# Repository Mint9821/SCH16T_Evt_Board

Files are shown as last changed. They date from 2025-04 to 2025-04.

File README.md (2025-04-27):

# SCH16T_Evt_Board

Murata製IMUであるSCH16Tシリーズの開発ボード
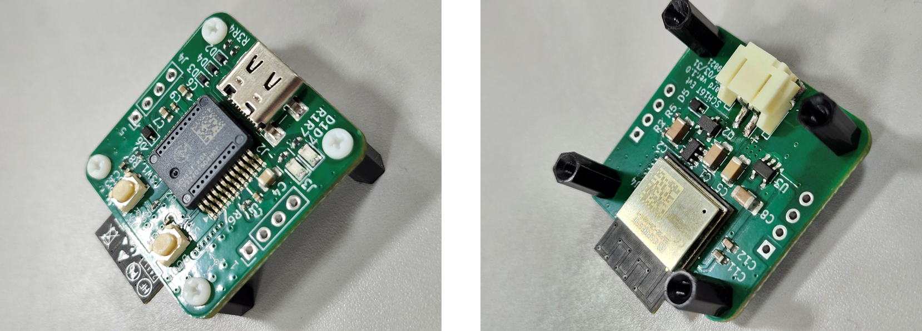
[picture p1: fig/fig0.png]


## システム構成図
本基板のシステム構成図を次に示す。
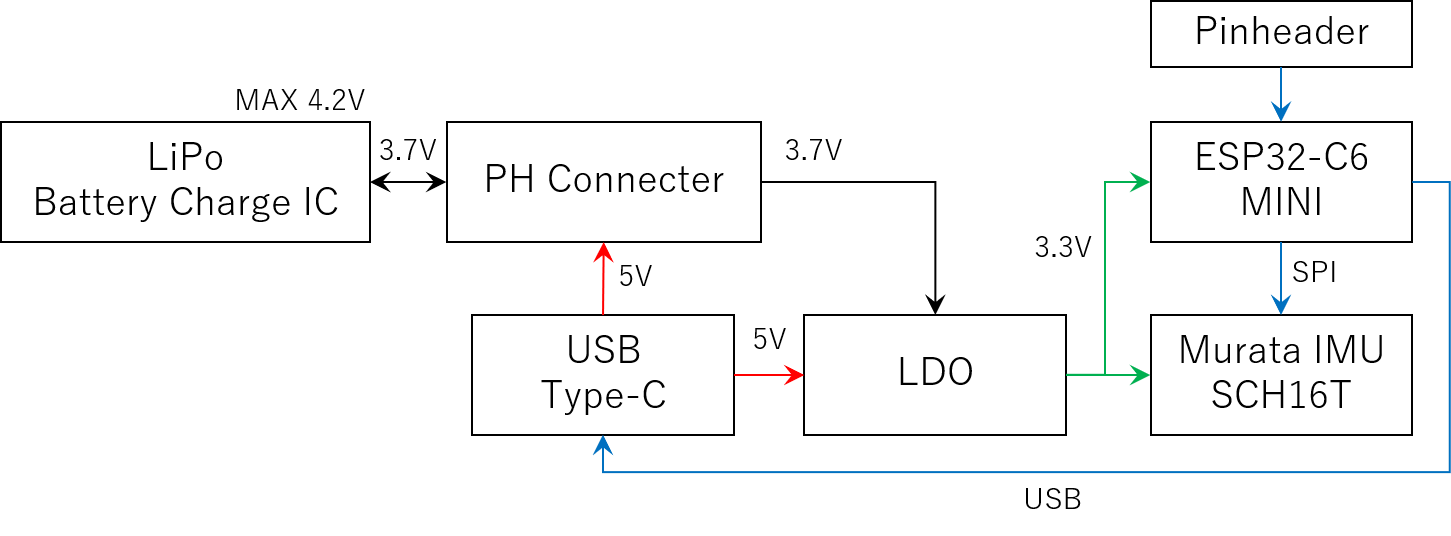
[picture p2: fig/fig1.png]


### 電源構成
USB-TypeCから5Vを給電でき、1SのLiPoバッテリを充電する機能を有する。
LiPoバッテリの充電中は、USBからの給電でマイコン及びIMUは駆動する。
LiPoバッテリが接続された状態でUSBを抜くと、LiPoバッテリからの給電に切り替わる。
5Vまたは3.7Vは低損失LDOによって3.3Vまで降圧される。

### 通信
マイコンとIMUはSPI通信で接続される。
また、マイコンからUSB-TypeCにはUSB通信で接続される。
マイコンにプログラムを書き込む場合は、USB-TypeCとPCを接続して行う。

## 1S LiPoバッテリの充電回路
先述した通り、USBコネクタを接続している間はLiPoバッテリが給電される。
回路動作の確認にはLTSpiceを用いて検証した。
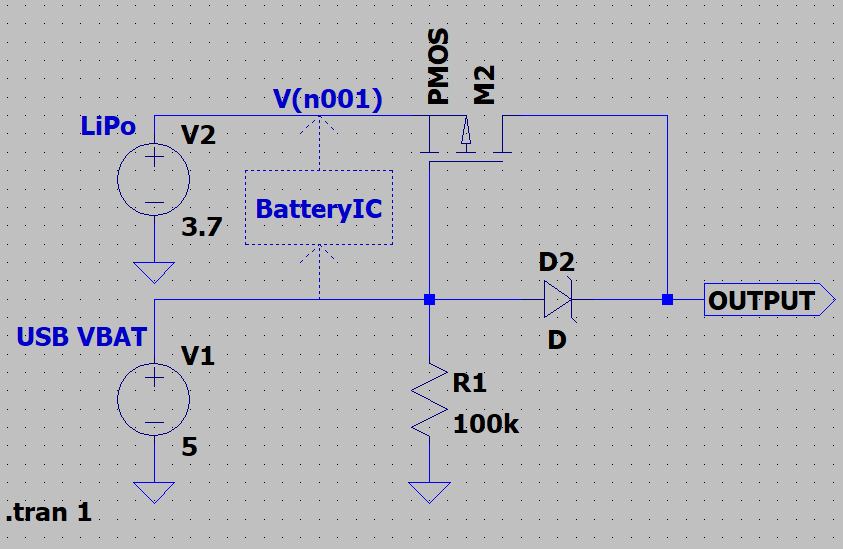
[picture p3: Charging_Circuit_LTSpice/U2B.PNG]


USB接続時の波形は次の通りである。
USB VBATが5Vを給電している場合、OUTPUTは約5Vを出力しており、V(n001)は約3.7Vになっている。
なお、実回路状ではV(n001)はLiPoバッテリの充電状況で変動する。
今回使用するバッテリ充電IC”MCP73831”の最大充電電圧は4.2Vである。
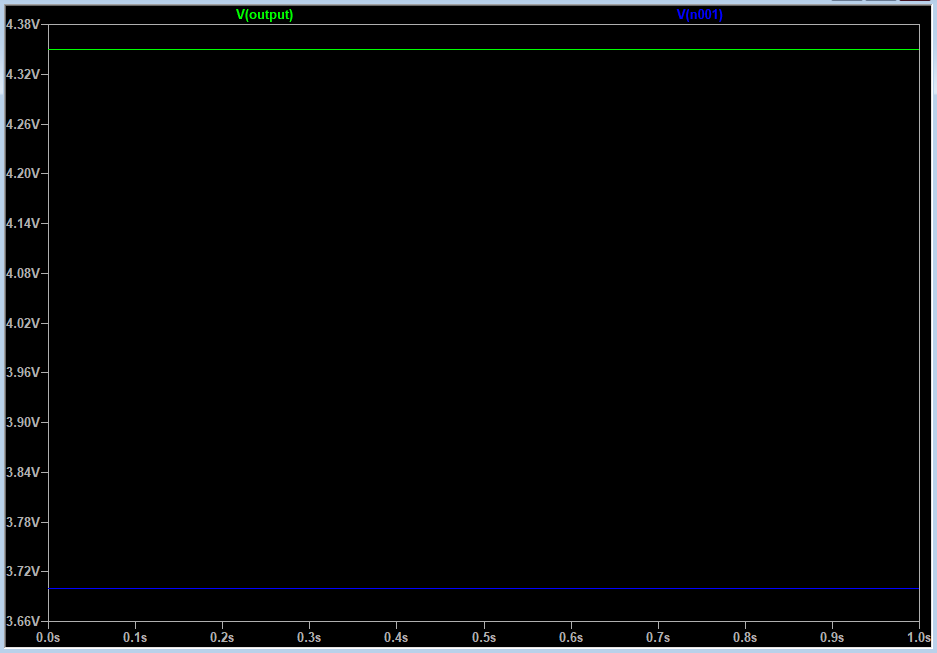
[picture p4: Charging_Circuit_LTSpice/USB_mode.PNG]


LiPoバッテリ接続時(USBコネクタ非接続)の波形は次の通りである。
OUTPUTは約3.7Vを出力しており、V(n001)は約3.7Vになっている。
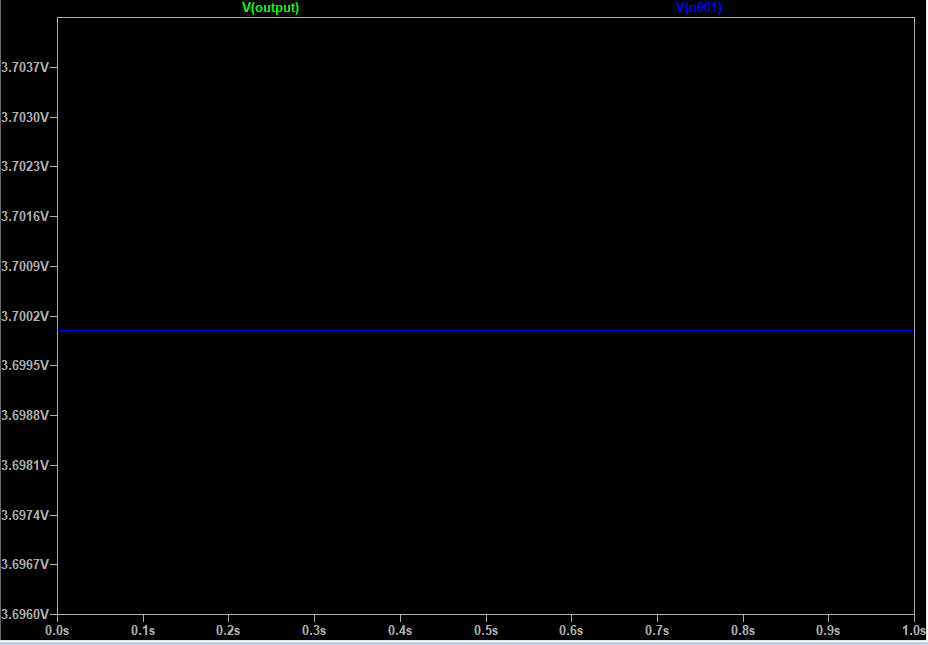
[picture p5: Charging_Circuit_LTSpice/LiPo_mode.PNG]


## IMU周辺回路
IMUであるMurata製SCH16Tシリーズの周辺回路は、公式サイトのアプリケーションノート(SCH16T series chip carrier PCB spesification)に従う。
>https://www.murata.com/-/media/webrenewal/products/sensor/pdf/specification/sch16t-pcb-specification.ashx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

## 回路図
全体回路図を次に示す。
画像が見ずらい場合は、「sch16t_evt/schematic」内のPDFを参照のこと。
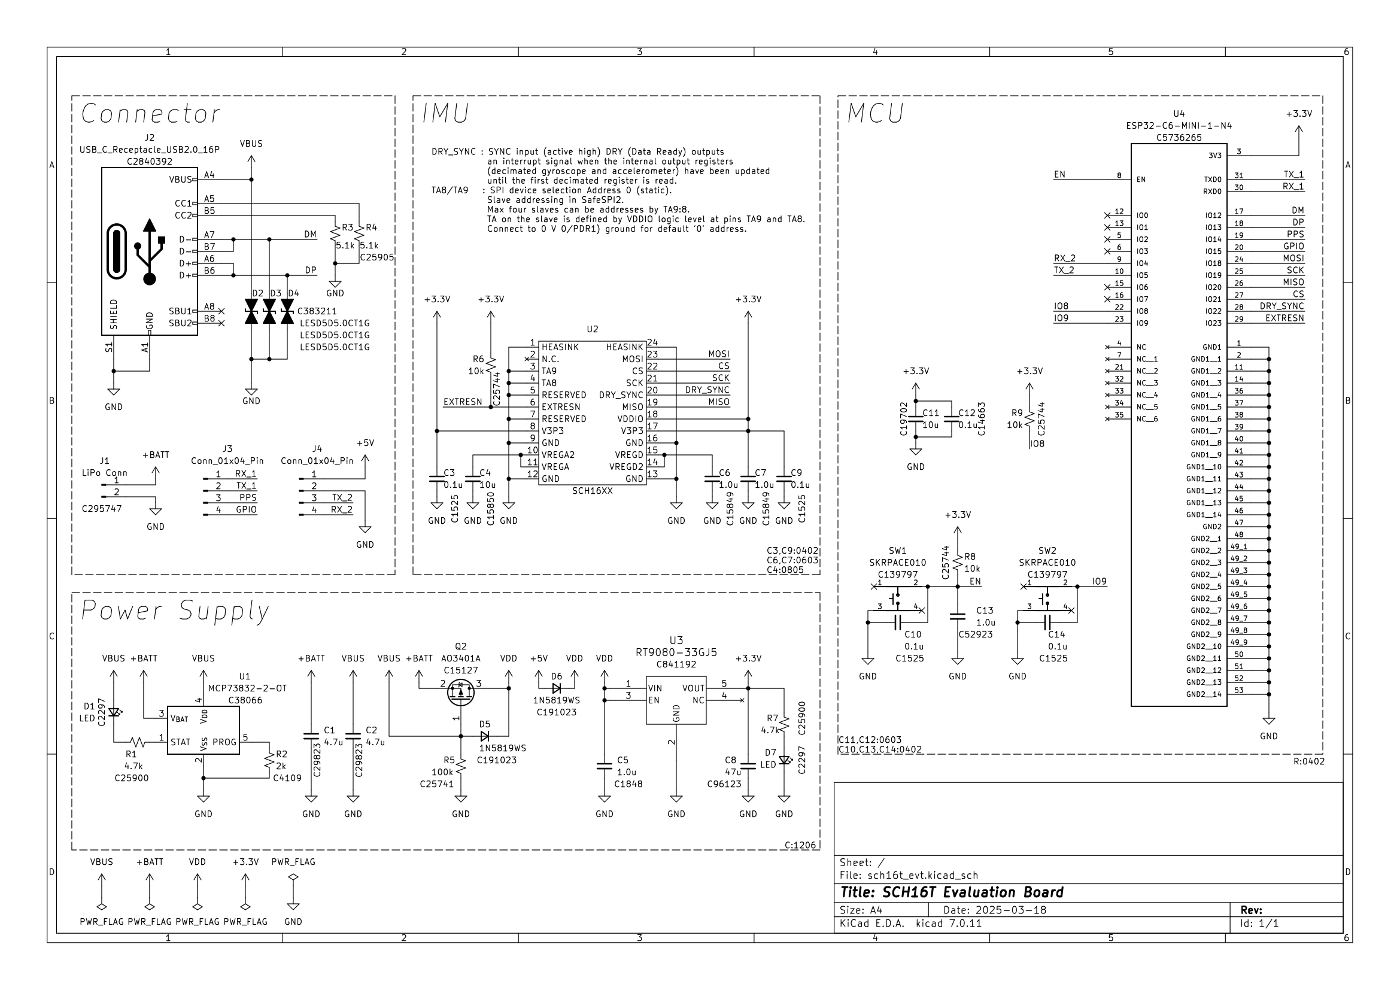
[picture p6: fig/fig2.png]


## ピンレイアウト
ピンアウトを下記の表に示す。
なお、ピン番号:5の+5Vは給電用であり、LiPoバッテリが接続されていても充電はされない。LiPoバッテリの接続中にピン番号:5への給電は非推奨。

| ピン番号 | ピンアサイン |
| ---- | ---- |
| 1 | ESP32 UART RX1(RXD0) |
| 2 | ESP32 UART TX1(TXD0) |
| 3 | PPS(IO14) |
| 4 | ESP32 GPIO(IO15) |
| 5 | +5V |
| 6 | GND |
| 7 | ESP32 UART TX2(IO5) |
| 8 | ESP32 UART RX2(IO4) |

## 発注する場合
基板の製造および、部品実装に必要なデータは「sch16t_evt/SCH16T_evt_board_ver_1_1」に保存されている。
JLCPCBのみ対応しており、SCH16Tだけは現状自分で用意する必要がある。
それ以外の部品は、JLCPCBAに対応する(2025年4月時点)。

## KiCadライブラリ
本開発ボードではKiCadの既存ライブラリに加えて、SCH16XXとESP32-C6-MINI-1-N4を使用しています。
KiCadファイルを編集する際は、各自でライブラリを適用してください。

### SCH16XX
自作です、じゆうにつかっていいよ(一応、MITライセンスに従います)。

>MIT License
>
>Copyright (c) [2024] [Mint9821]
>
>Permission is hereby granted, free of charge, to any person obtaining a copy
of this library and associated files, to deal in the library without restriction, including without limitation the rights to use, copy, modify, merge, publish, distribute, sublicense, and/or sell copies of the library...

### ESP32-C6-MINI-1-N4
公開されているライブラリを使用。
KiCadの回路図およびPCBを開く際は下記URLからライブラリをダウンロードした後に適用してください。

>https://www.snapeda.com/parts/ESP32-C6-MINI-1-N4/Espressif%20Systems/view-part/

>このリポジトリには、SnapMagic Search, Inc. が提供するモデルを含んでいます。
モデルの使用にあたっては、[SnapMagic Model License](URL) に従ってください。
モデル単体での再配布は禁止されています。

### その他ライブラリ

>本設計はKiCad公式ライブラリを使用しています。
ライブラリはCC BY-SA 4.0のライセンスの下に配布されています。
https://creativecommons.org/licenses/by-sa/4.0/

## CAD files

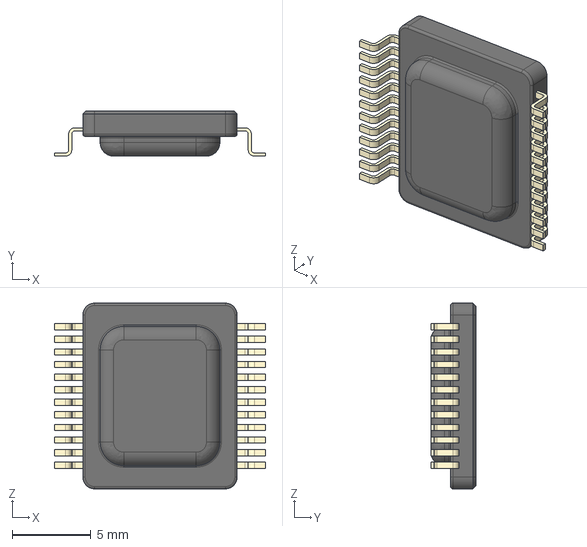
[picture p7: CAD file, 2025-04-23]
KiCad_lib/SCH16XX/SCH16XX.step
13.4 x 2.87 x 11.8 mm

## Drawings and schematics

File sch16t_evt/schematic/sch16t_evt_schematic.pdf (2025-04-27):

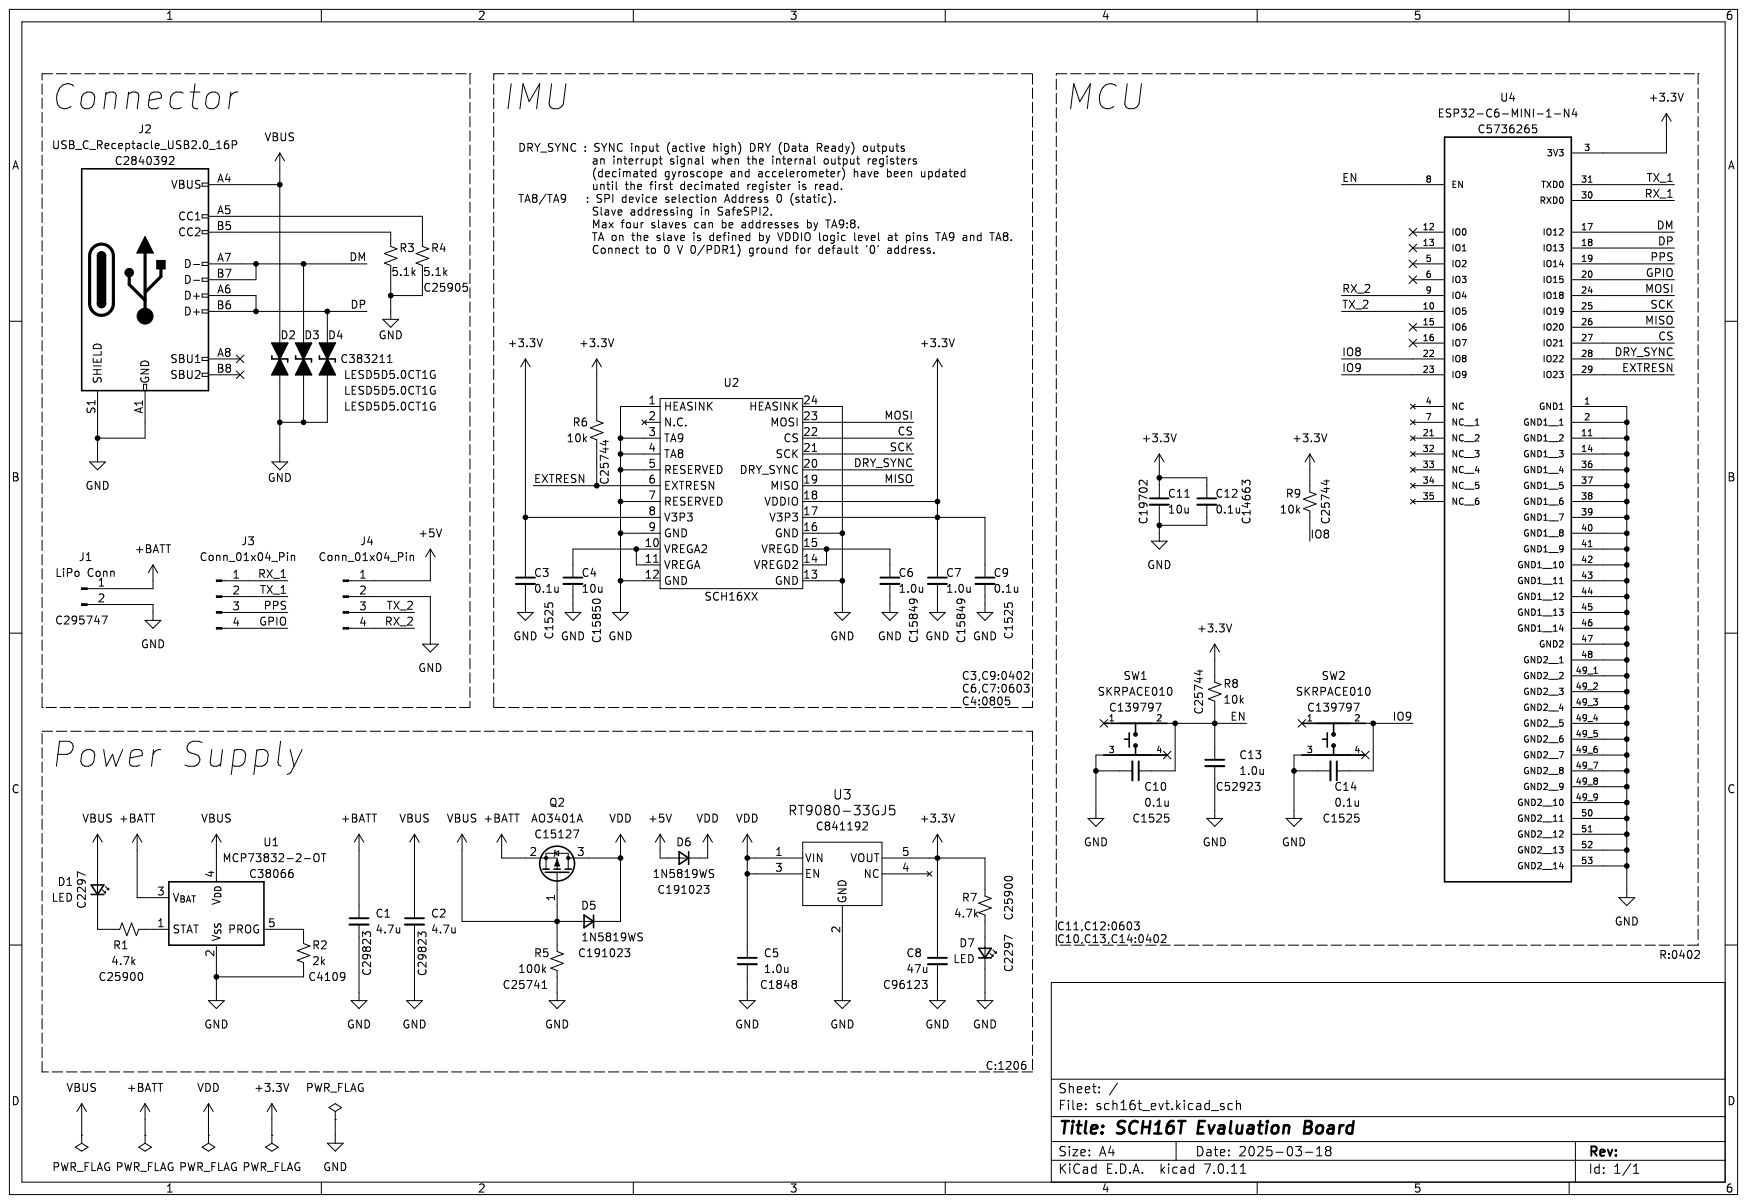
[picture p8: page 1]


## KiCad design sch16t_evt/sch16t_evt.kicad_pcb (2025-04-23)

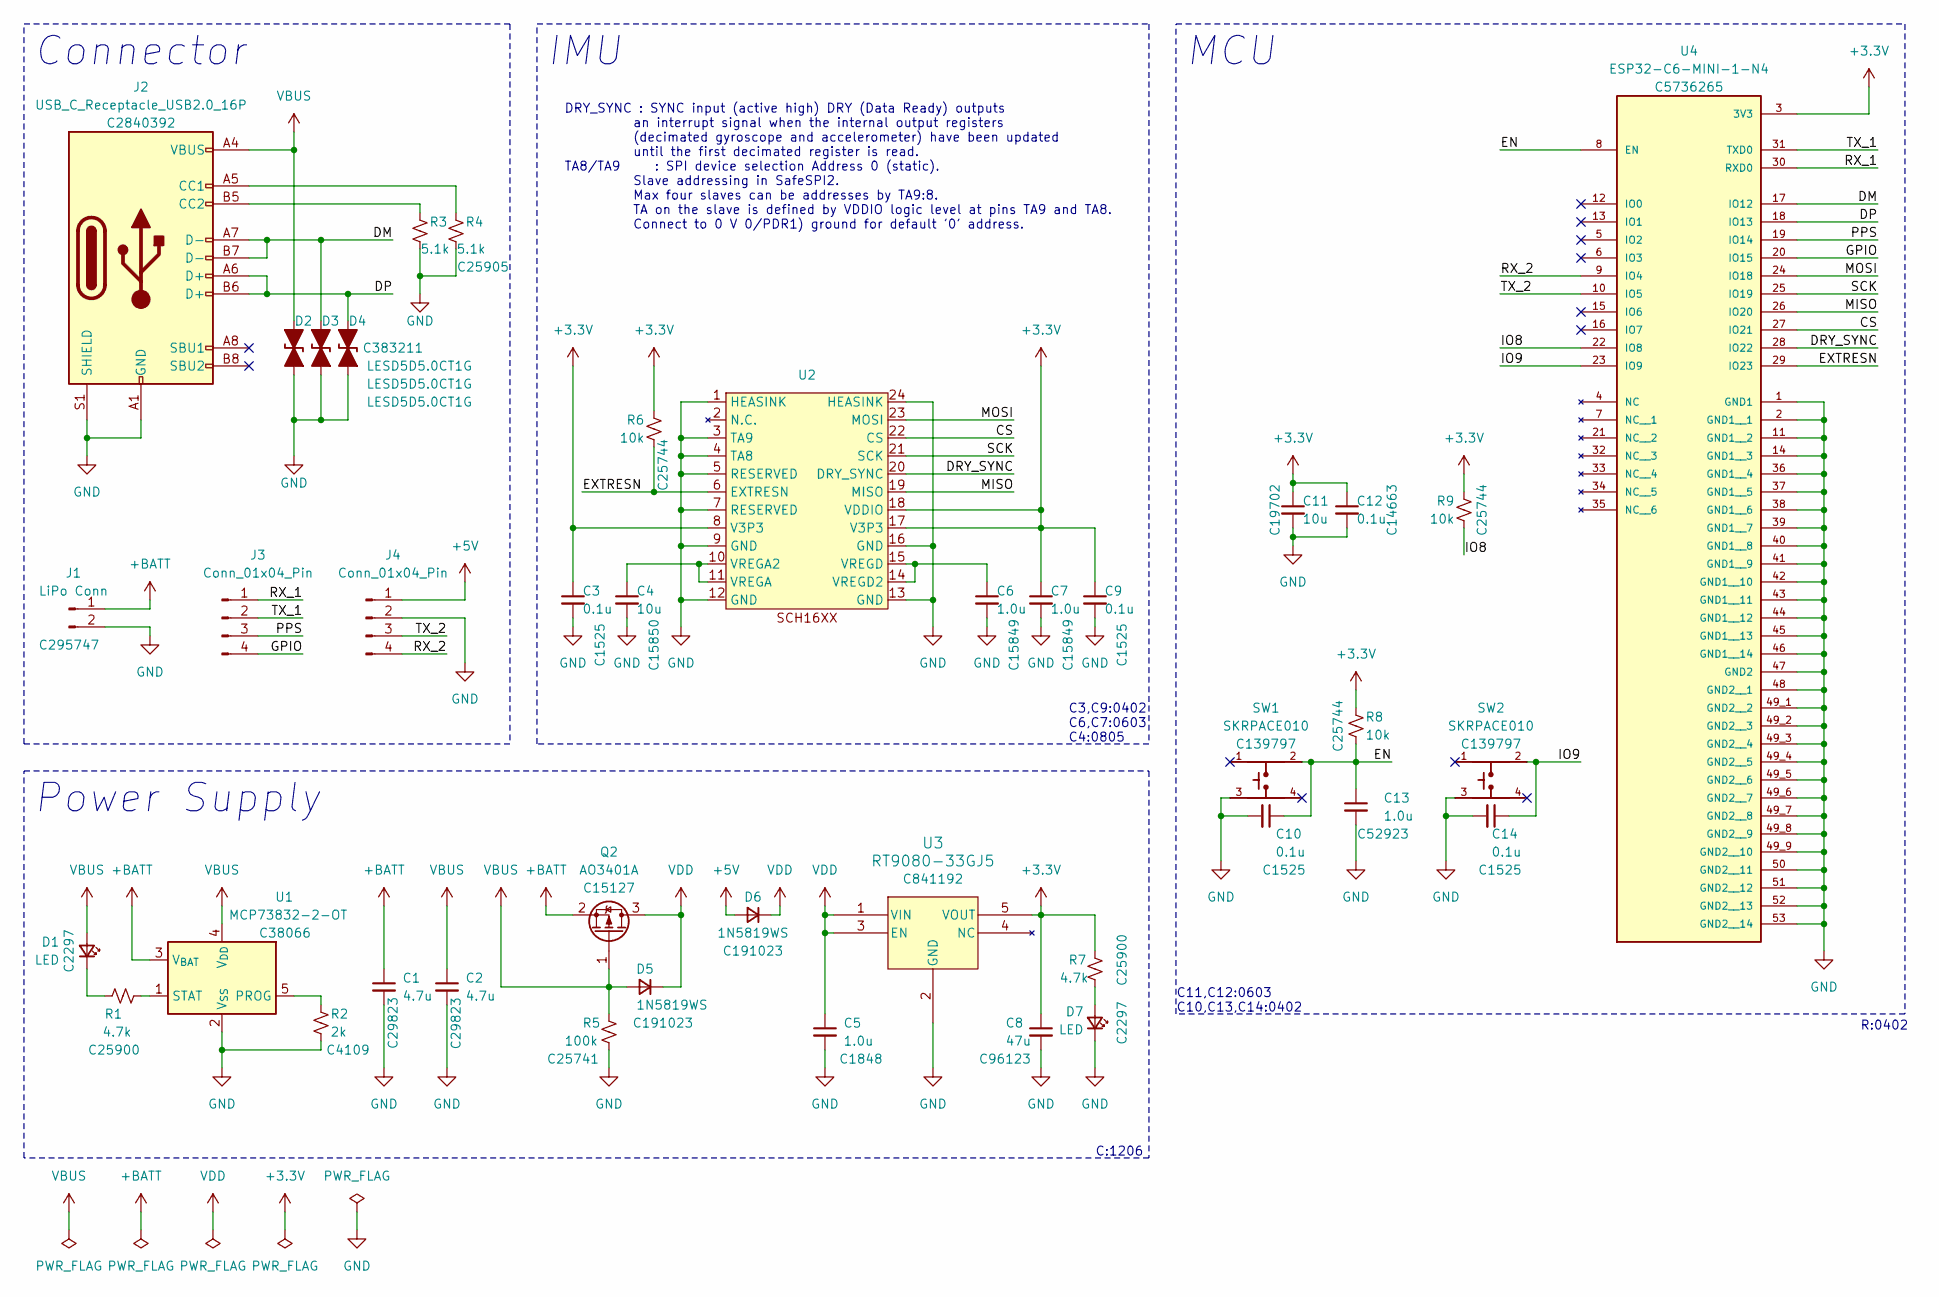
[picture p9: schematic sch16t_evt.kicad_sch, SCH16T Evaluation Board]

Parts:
C1, C2: 4.7u; C_1206_3216Metric; LCSC C29823
C3, C9, C10, C14: 0.1u; C_0402_1005Metric; LCSC C1525
C4: 10u; C_0805_2012Metric; LCSC C15850
C5: 1.0u; C_1206_3216Metric; LCSC C1848
C6, C7: 1.0u; C_0603_1608Metric; LCSC C15849
C8: 47u; C_1206_3216Metric; LCSC C96123
C11: 10u; C_0603_1608Metric; LCSC C19702
C12: 0.1u; C_0603_1608Metric; LCSC C14663
C13: 1.0u; C_0402_1005Metric; LCSC C52923
D1, D7: LED; D_0805_2012Metric; LCSC C2297
D2, D3, D4: LESD5D5.0CT1G; D_SOD-523; LCSC C383211
D5, D6: 1N5819WS; D_SOD-323; LCSC C191023
J1: LiPo Conn; JST_PH_S2B-PH-SM4-TB_1x02-1MP_P2.00mm_Horizontal; LCSC C295747
J2: USB_C_Receptacle_USB2.0_16P; USB_C_Receptacle_GCT_USB4110; LCSC C2840392
J3, J4: Conn_01x04_Pin; PinHeader_1x04_P2.54mm_Vertical
Q2: AO3401A; SOT-23; LCSC C15127
R1, R7: 4.7k; R_0402_1005Metric; LCSC C25900
R2: 2k; R_0402_1005Metric; LCSC C4109
R3, R4: 5.1k; R_0402_1005Metric; LCSC C25905
R5: 100k; R_0402_1005Metric; LCSC C25741
R6, R8, R9: 10k; R_0402_1005Metric; LCSC C25744
SW1, SW2: SKRPACE010; SW_SKRPACE010; LCSC C139797
U1: MCP73832-2-OT; SOT-23-5; LCSC C38066
U2: SCH16XX
U3: RT9080-33GJ5; SOT-23-5; LCSC C841192
U4: ESP32-C6-MINI-1-N4; XCVR_ESP32-C6-MINI-1-N4; PARTREV 1.0; LCSC C5736265

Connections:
+3.3V: C3.1, C7.1, C8.1, C9.1, C11.1, C12.1, R6.2, R7.1, R8.1, R9.2, U2.8 (V3P3), U2.17 (V3P3), U2.18 (VDDIO), U3.5 (VOUT), U4.3 (3V3)
+5V: D6.2 (A), J4.1
+BATT: C1.1, J1.1, Q2.2 (S), U1.3 (V_{BAT})
/CS: U2.22 (CS), U4.27 (IO21)
/DM: D3.2 (A2), J2.A7 (D-), J2.B7 (D-), U4.17 (IO12)
/DP: D4.2 (A2), J2.A6 (D+), J2.B6 (D+), U4.18 (IO13)
/DRY_SYNC: U2.20 (DRY_SYNC), U4.28 (IO22)
/EN: C10.1, C13.1, R8.2, SW1.2, U4.8 (EN)
/EXTRESN: R6.1, U2.6 (EXTRESN), U4.29 (IO23)
/GPIO: J3.4, U4.20 (IO15)
/IO8: R9.1, U4.22 (IO8)
/IO9: C14.1, SW2.2, U4.23 (IO9)
/MISO: U2.19 (MISO), U4.26 (IO20)
/MOSI: U2.23 (MOSI), U4.24 (IO18)
/PPS: J3.3, U4.19 (IO14)
/RX_1: J3.1, U4.30 (RXD0)
/RX_2: J4.4, U4.9 (IO4)
/SCK: U2.21 (SCK), U4.25 (IO19)
/TX_1: J3.2, U4.31 (TXD0)
/TX_2: J4.3, U4.10 (IO5)
GND: C1.2, C2.2, C3.2, C4.2, C5.2, C6.2, C7.2, C8.2, C9.2, C10.2, C11.2, C12.2, C13.2, C14.2, D2.1 (A1), D3.1 (A1), D4.1 (A1), D7.1 (K), J1.2, J2.A1 (GND), J2.A12 (GND), J2.B1 (GND), J2.B12 (GND), J2.S1 (SHIELD), J4.2, R2.2, R3.2, R4.2, R5.2, SW1.3, SW2.3, U1.2 (V_{SS}), U2.1 (HEASINK), U2.3 (TA9), U2.4 (TA8), U2.5 (RESERVED), U2.7 (RESERVED), U2.9 (GND), U2.12 (GND), U2.13 (GND), U2.16 (GND), U2.24 (HEASINK), U3.2 (GND), U4.1 (GND1), U4.2 (GND1__1), U4.11 (GND1__2), U4.14 (GND1__3), U4.36 (GND1__4), U4.37 (GND1__5), U4.38 (GND1__6), U4.39 (GND1__7), U4.40 (GND1__8), U4.41 (GND1__9), U4.42 (GND1__10), U4.43 (GND1__11), U4.44 (GND1__12), U4.45 (GND1__13), U4.46 (GND1__14), U4.47 (GND2), U4.48 (GND2__1), U4.49_1 (GND2__2), U4.49_2 (GND2__3), U4.49_3 (GND2__4), U4.49_4 (GND2__5), U4.49_5 (GND2__6), U4.49_6 (GND2__7), U4.49_7 (GND2__8), U4.49_8 (GND2__9), U4.49_9 (GND2__10), U4.50 (GND2__11), U4.51 (GND2__12), U4.52 (GND2__13), U4.53 (GND2__14)
unnamed: D1.1 (K), R1.1
unnamed: D7.2 (A), R7.2
unnamed: J2.A5 (CC1), R4.1
unnamed: J2.B5 (CC2), R3.1
unnamed: R2.1, U1.5 (PROG)
unnamed: R1.2, U1.1 (STAT)
unnamed: C4.1, U2.10 (VREGA2), U2.11 (VREGA)
unnamed: C6.1, U2.14 (VREGD2), U2.15 (VREGD)
VBUS: C2.1, D1.2 (A), D2.2 (A2), D5.2 (A), J2.A4 (VBUS), J2.A9 (VBUS), J2.B4 (VBUS), J2.B9 (VBUS), Q2.1 (G), R5.1, U1.4 (V_{DD})
VDD: C5.1, D5.1 (K), D6.1 (K), Q2.3 (D), U3.1 (VIN), U3.3 (EN)

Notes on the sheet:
Power Supply
MCU
IMU
DRY_SYNC : SYNC input (active high) DRY (Data Ready) outputs an interrupt signal when the internal output registers (decimated gyroscope and accelerometer) have been updated until the first decimated register is read. TA8/TA9 : SPI device selection Address 0 (static). Slave addressing in SafeSPI2. 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
Connector
C:1206
C11,C12:0603 C10,C13,C14:0402
C3,C9:0402 C6,C7:0603 C4:0805
R:0402

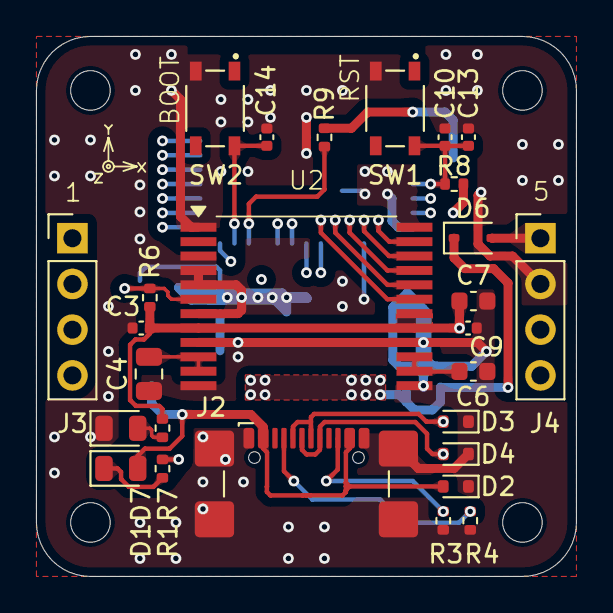
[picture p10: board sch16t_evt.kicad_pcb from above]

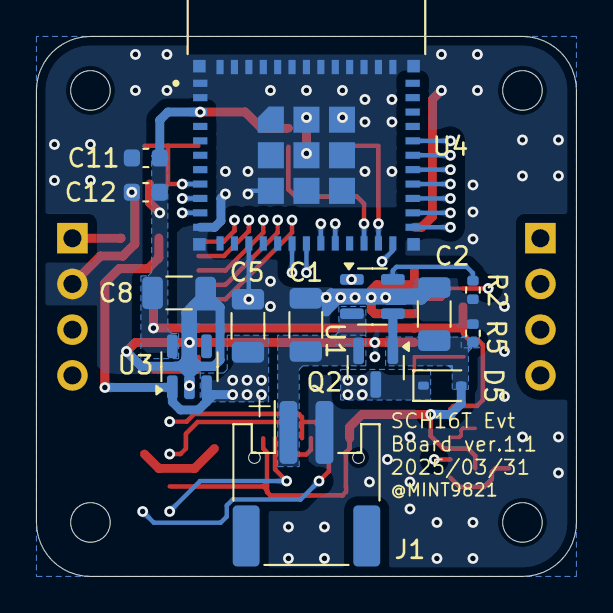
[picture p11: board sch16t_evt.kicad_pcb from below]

Board: 4 copper layers, 30.0 x 30.0 mm, 41 parts (14 on the bottom side), 31 nets.

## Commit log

2025-04-23 Readme編集
2025-04-23 Kicad files
    [SCH16XX.step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]
2025-04-23 chenage LiPo_charge_files and Readme
